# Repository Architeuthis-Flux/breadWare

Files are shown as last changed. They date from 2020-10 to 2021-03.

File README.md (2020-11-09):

# breadWare

Hey guys, here's the PCB layout for the switch matrix board. Those holes should line up with the columns on a breadboard so this whole thing can be soldered directly onto the bottom. I just ordered 10 of these boards (in red soldermask! I've never been patient enough to wait the extra 24-48 hours to do a color other than green) so we can put a few together (I can teach whoever's interested how to hot air solder these surface mount parts) and then get on making those header pins on the sides move the correct number of electrons to make this thing work.
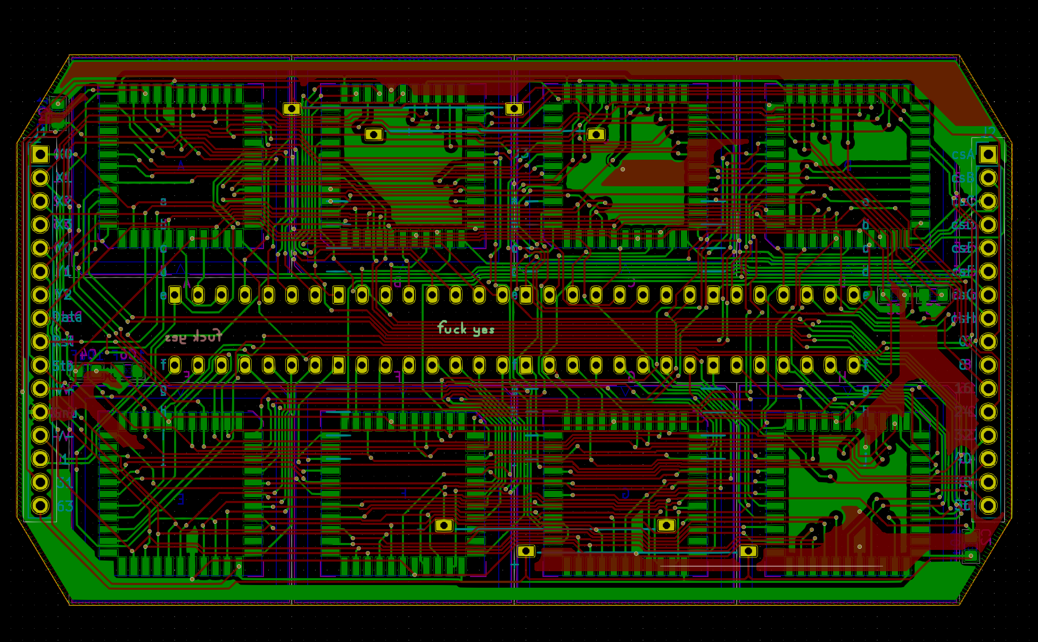
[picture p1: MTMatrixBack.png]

#
 
That white rectangle is roughly the size of a breadboard. We might be able to get the size down if we use [TQFP](https://en.wikipedia.org/wiki/Quad_flat_package) instead of these huge [PLCC](https://en.wikipedia.org/wiki/Chip_carrier#Plastic-leaded_chip_carrier) sockets. Also could someone who reads chinese look through [this datasheet](https://datasheet.lcsc.com/szlcsc/Jiangsu-Qin-Heng-CH446Q_C109471.pdf) for the [CH446Q](http://www.wch-ic.com/products/CH446.html) and tell me if there are any significant differences from [MT8816](http://images.100y.com.tw/pdf_file/41-ZARLINK-MT8816.pdf) that we're using? Because the [JLCPCB](https://jlcpcb.com/) (who is making these boards for us) has the CH446Q in stock and they'll make the board and then solder them on so we can just order fully assembled boards ridiculously cheap (and the chips themselves are ~$1, so like a quarter of the price.)
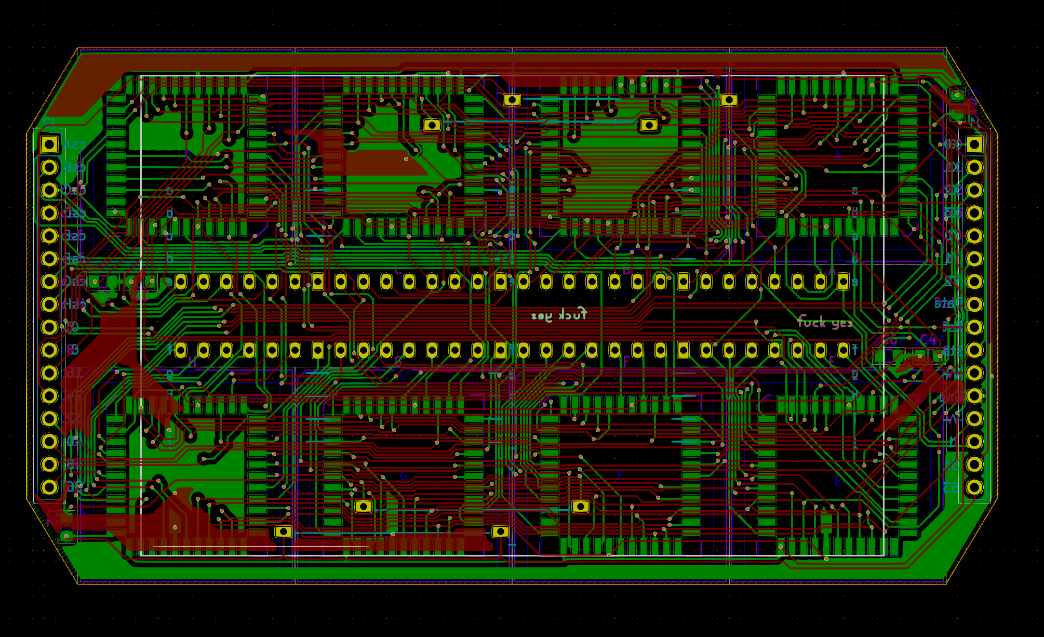
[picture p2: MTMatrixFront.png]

#
 
Notice how some of the pads in the middle (Plated Through Holes or PTH is the correct term just so you know) are more square and others are rounded. The squarer ones means that that pin is connected to the headers on the sides, so it can be used for measurement or power or whatever we decide when we make the control board. Those pins are: 0,1,8,16,24,31,32,40,48,56,63 which is the Y0 pin on each chip plus the ones that end up on the edges of the breadboard (31,63) and 1 because I had an extra header pin available. 
Pin 0 is connected to the Negative rail on the top of the breadboard, 31 is the top Positive rail, 32 is the bottom Negaitve rail, and 63 is the bottom Positive rail. Everything else is where you'd expect it to be.
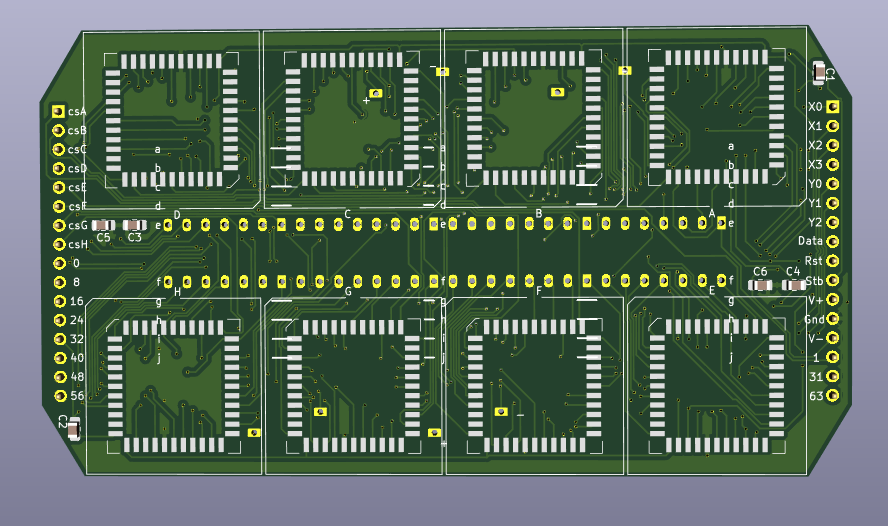
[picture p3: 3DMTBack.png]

#
 
Yes, these pin headers are on the wrong side but I'm not gonna let some stupid auto-generated 3D model tell me which side to solder them on. I might spend some time finding the 3D models for the PLCC sockets and a breadboard so this looks closer to the real thing.
Also, notice the silkscreened lines on the top and bottom are just a bit off from the holes, turns out the power rails on a breadboard arent spaced perfectly on the same grid as the rest of the pins. The line is marked where it would be if the universe made any sense.
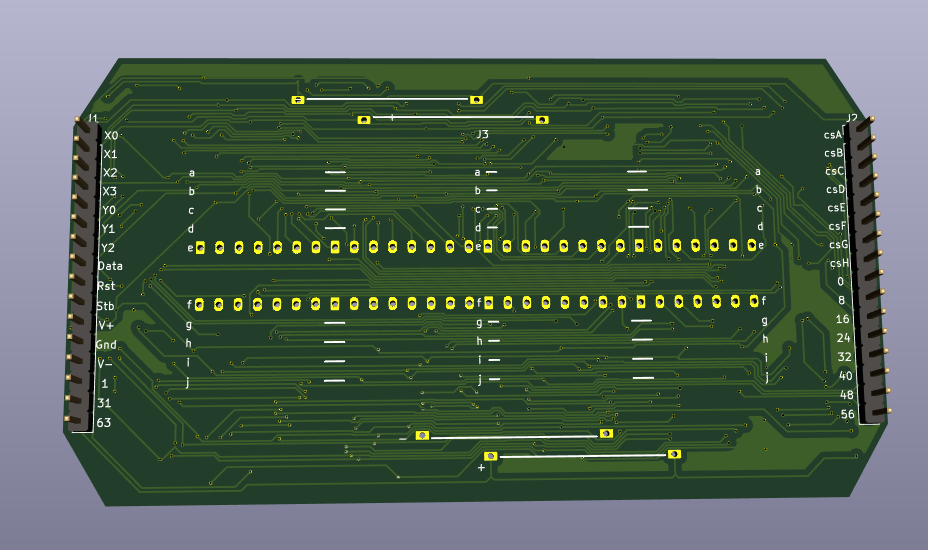
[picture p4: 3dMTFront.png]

#
 
Those letters along the middle correspond to the row labels on a breadboard.
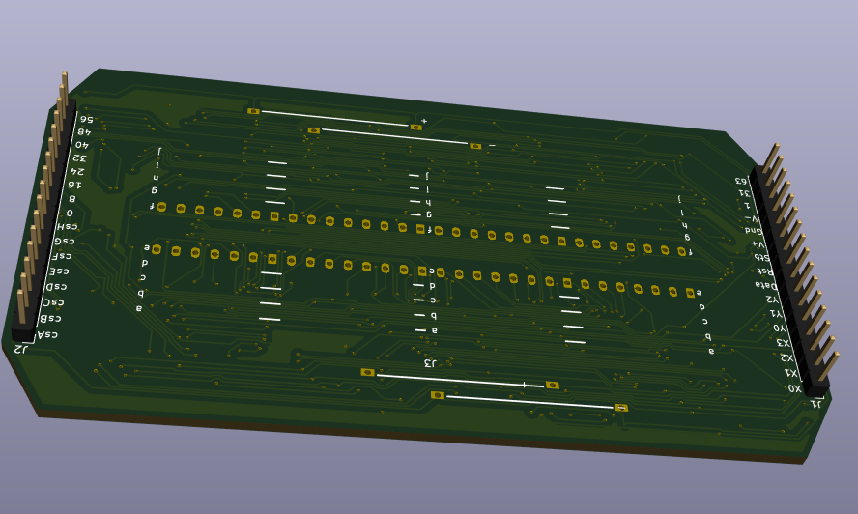
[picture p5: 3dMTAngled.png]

#
  
Here's a zoomed out view of the whole schematic, those blue lines are busses, so they're actually 4 wires bundled together to make it look less messy. This is following JJ's brilliant idea for how to connect everything except I looped the ends back around so they conceptually should be thought of as a ring, If someone wants to map that out on one of those [Ring Lattice Graphs](https://i.imgur.com/oiiyKlz.png), it might make all this easier to visualize.
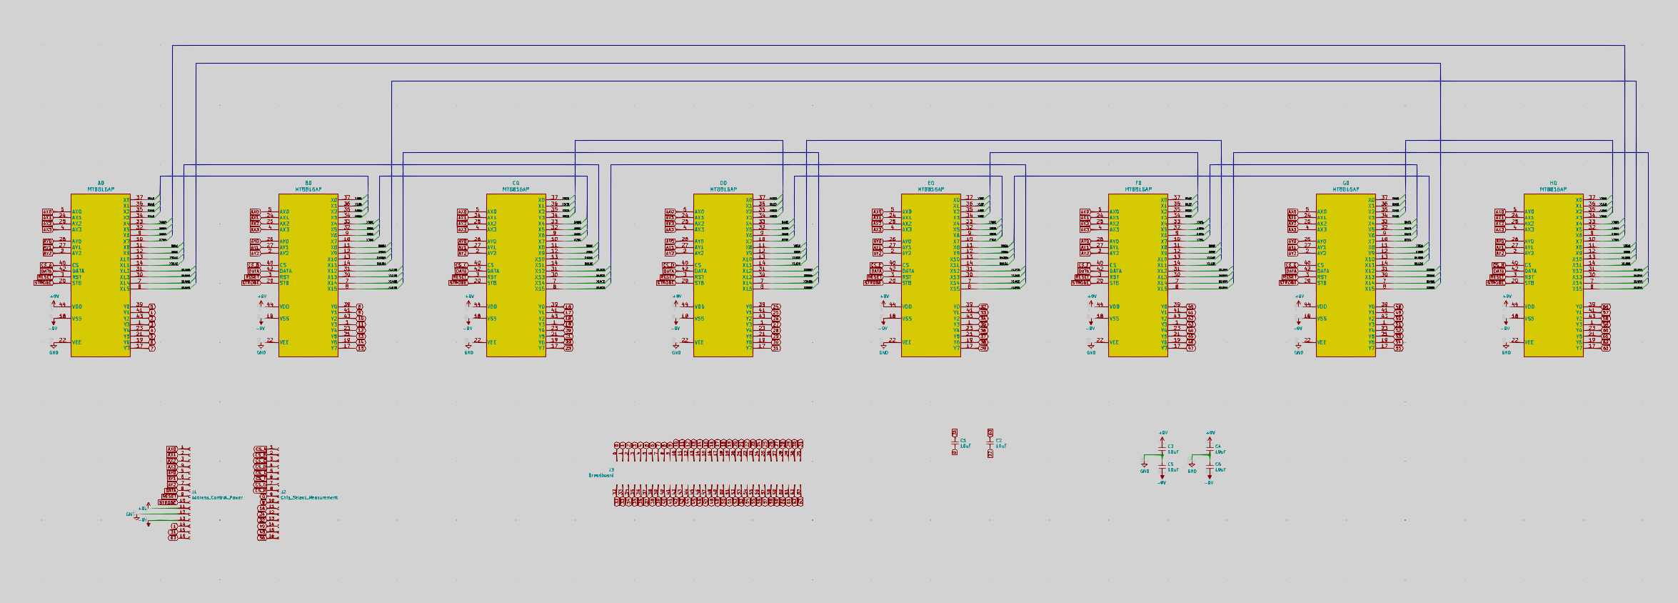
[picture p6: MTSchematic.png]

#

On the left we have the address lines, control lines and power input. Except for the last three with numbers, these are connected to all 8 chips together, so to make just the one we want to control do stuff, we use the Chip Select lines on the right side (labeled CS_A-H) which are wired to each chip individually. If the CS is logic 0 (~0 Volts, LOW, whatever), that chip will ignore everything that's put on the address and control lines because that signal isn't meant for it and these chips ain't no eavesdroppin' bitches. (just for everyone's learning, Chip Select lines seem to almost always be Active Low, meaning they'll ignore everything when that pin is held at logic 1 (5V or 3.3V depending on the chip) which is denoted with a line above, C̅S̅ (or /CS because overlining text is a pain in the ass on a computer. and it's typically spoken as "bar", so "CS Bar" in this case) this chip is unusual because it's Active High.)
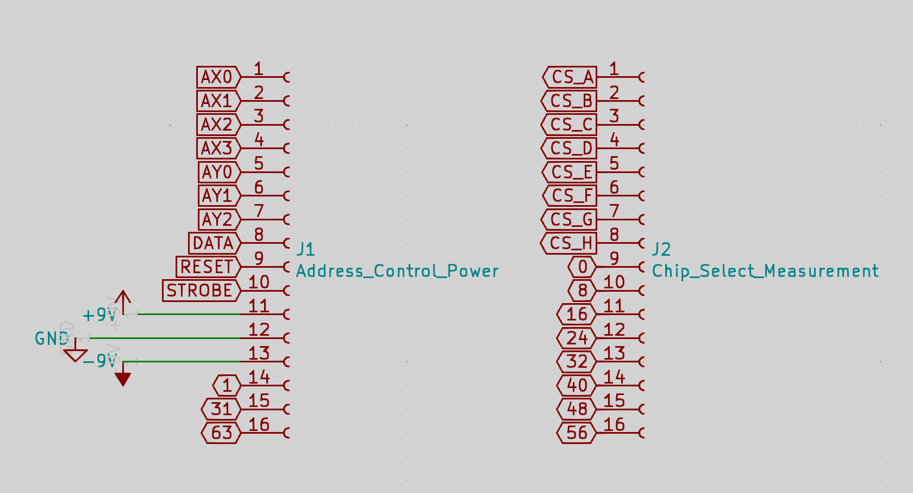
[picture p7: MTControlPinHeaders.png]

#
 
Here's a zoomed part so you can see how I named these interconnects, it goes Pin Name (X0, X1, etc.) then the letters of the two chips it's connecting (in alpabetical order). So the pin labeled X0CD connects pin X0 on chip C to pin X0 on chip D. I had to do this like 5 times to get the wires to always connect to the same pin on both chips, but it should make the software much easier to deal with. 
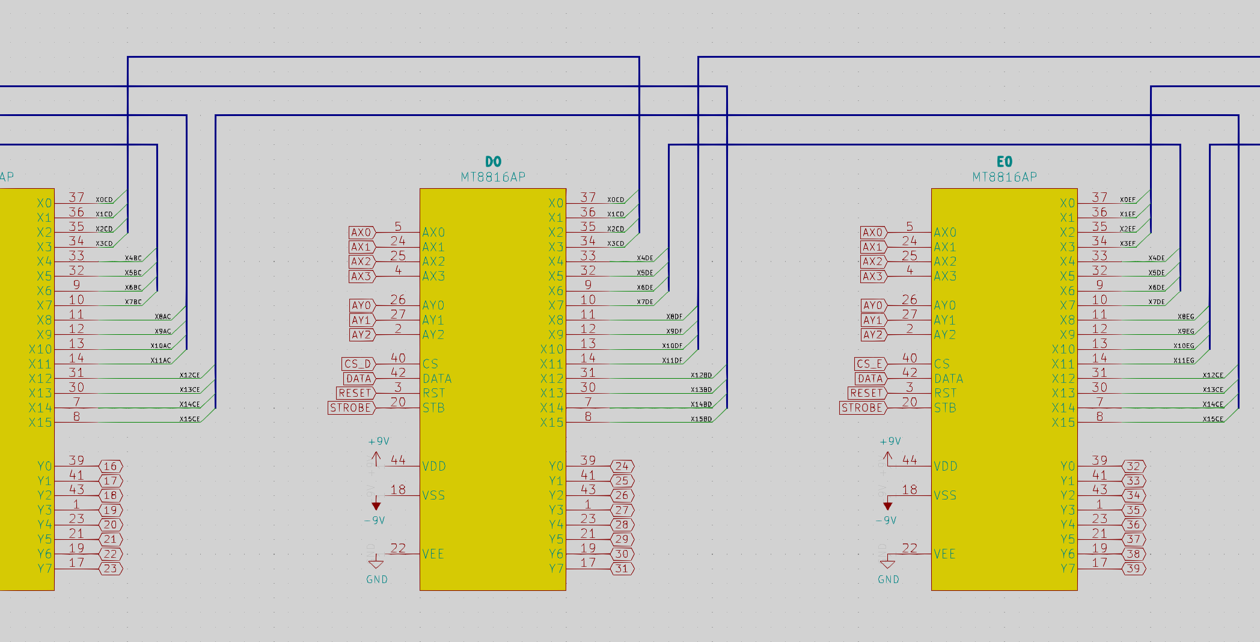
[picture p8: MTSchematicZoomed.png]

#
  
Here's the table I used to figure out which chips are connected where, and this helped me put them all in alphabetical order (because I can't tell you if F is before or after H without singing the alpabet song in my head every time) so the labels are the same on both sides of the wire. Each chip is connected the to the two before and after it. 
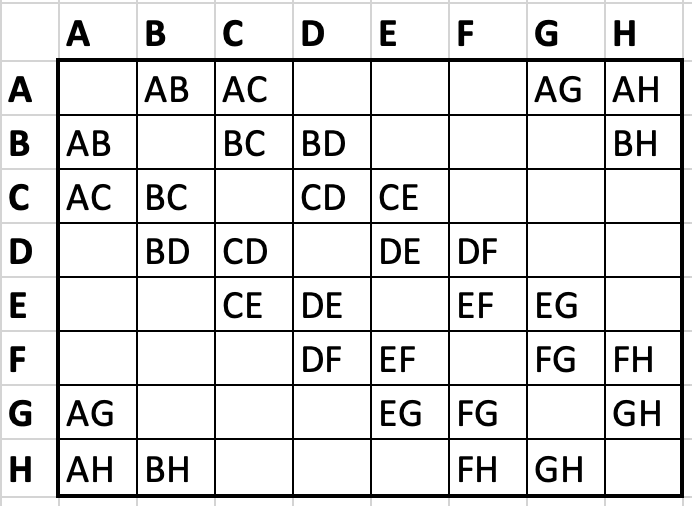
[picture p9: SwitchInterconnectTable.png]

#
One day we will have this piece of paper framed and signed by JJ.
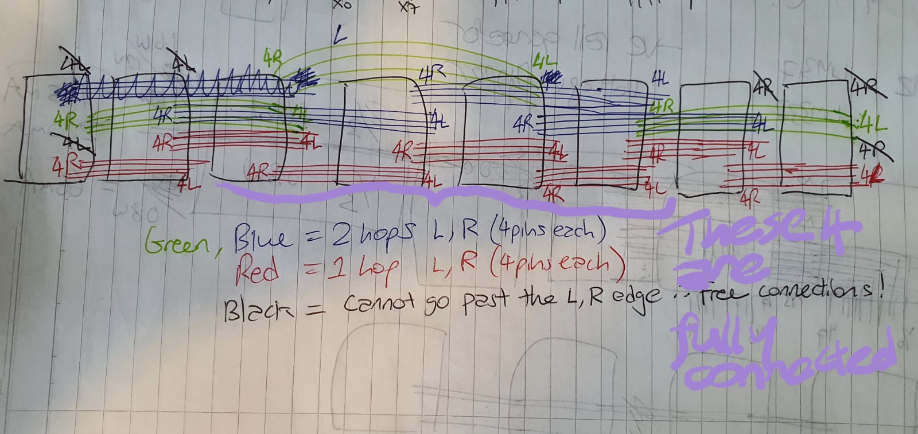
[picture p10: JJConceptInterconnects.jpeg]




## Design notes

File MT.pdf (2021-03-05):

Chip Breadboard
Row

Internal Pin

Number | MT Pin Y | X Pin Chip
Connection
MT Pin X | Notes
A | 0 | 0 | B | 0 | Top GND
A | 1 | 1 | 1 | B | 1
A | 2 | 2 | 2 | B | 2
A | 3 | 3 | 3 | B | 3
A | 4 | 4 | 4 | H | 4
A | 5 | 5 | 5 | H | 5
A | 6 | 6 | 6 | H | 6
A | 7 | 7 | 7 | H | 7
A | C | 8
A | C | 9
A | C | 10
A | C | 11
A | G | 12
A | G | 13
A | G | 14
A | G | 15
B | 8 | 8 | 0 | A | 0
B | 9 | 9 | 1 | A | 1
B | 10 | 10 | 2 | A | 2
B | 11 | 11 | 3 | A | 3
B | 12 | 12 | 4 | C | 4
B | 13 | 13 | 5 | C | 5
B | 14 | 14 | 6 | C | 6
B | 15 | 15 | 7 | C | 7
B | H | 8
B | H | 9
B | H | 10
B | H | 11
B | D | 12
B | D | 13
B | D | 14
B | D | 15
C | 16 | 16 | 0 | D | 0
C | 17 | 17 | 1 | D | 1
C | 18 | 18 | 2 | D | 2
C | 19 | 19 | 3 | D | 3
C | 20 | 20 | 4 | B | 4
C | 21 | 21 | 5 | B | 5
C | 22 | 22 | 6 | B | 6
C | 23 | 23 | 7 | B | 7
C | A | 8
C | A | 9
C | A | 10

C

A | 11
C
E | 12
C
E | 13
C
E | 14
C
E | 15
D | 24 | 24

0

C

0
D | 25 | 25

1

C

1
D | 26 | 26

2

C

2
D | 27 | 27

3

C

3
D | 28 | 28

4

E

4
D | 29 | 29

5

E

5
D | 30 | 30

6

E

6
D | | 31

7

E

7 Top +5V
D

F

8
D

F

9
D
F | 10
D
F | 11
D
B | 12
D
B | 13
D
B | 14
D
B | 15
E | | 32

0

F

0 | Bottom GND
E | 1 | 33

1

F

1
E | 2 | 34

2

F

2
E | 3 | 35

3

F

3
E | 4 | 36

4

D

4
E | 5 | 37

5

D

5
E | 6 | 38

6

D

6
E | 7 | 39

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
G | 10
E
G | 11
E
C | 12
E
C | 13
E
C | 14
E
C | 15
F | 8 | 40

0

E

0
F | 9 | 41

1

E

1
F | 10 | 42

2

E

2
F | 11 | 43

3

E

3
F | 12 | 44

4

G

4
F | 13 | 45

5

G

5
F | 14 | 46

6

G

6
F | 15 | 47

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
D | 10
F
D | 11
F
H | 12
F
H | 13
F
H | 14
F
H | 15
G | 16 | 48

0

H

0
G | 17 | 49

1

H

1
G | 18 | 50

2

H

2
G | 19 | 51

3

H

3
G | 20 | 52

4

F

4
G | 21 | 53

5

F

5
G | 22 | 54

6

F

6
G | 23 | 55

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
E | 10
G
E | 11
G
A | 12
G
A | 13
G
A | 14
G
A | 15
H | 24 | 56

0

G

0
H | 25 | 57

1

G

1
H | 26 | 58

2

G

2
H | 27 | 59

3

G

3
H | 28 | 60

4

A

4
H | 29 | 61

5

A

5
H | 30 | 62

6

A

6
H | | 63

7

A

7 Bottom +5V
H

B

8
H

B

9
H
B | 10
H
B | 11
H
F | 12
H
F | 13
H
F | 14
H
F | 15

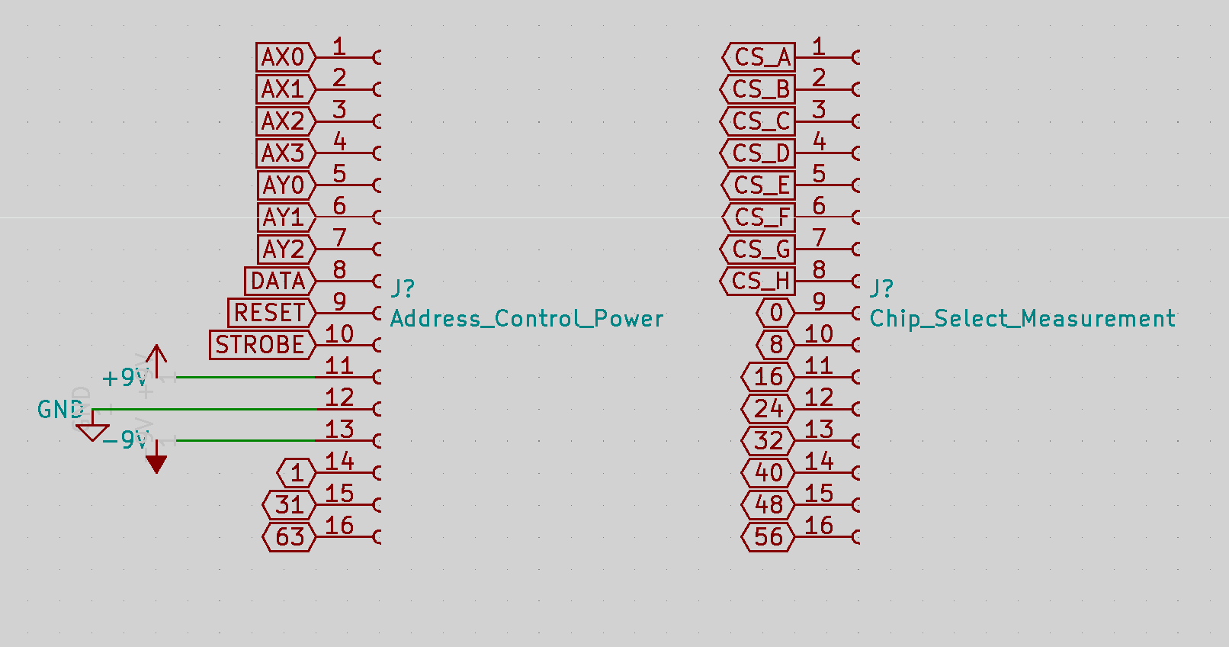
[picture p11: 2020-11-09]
MTMatrixPinHeaders.png

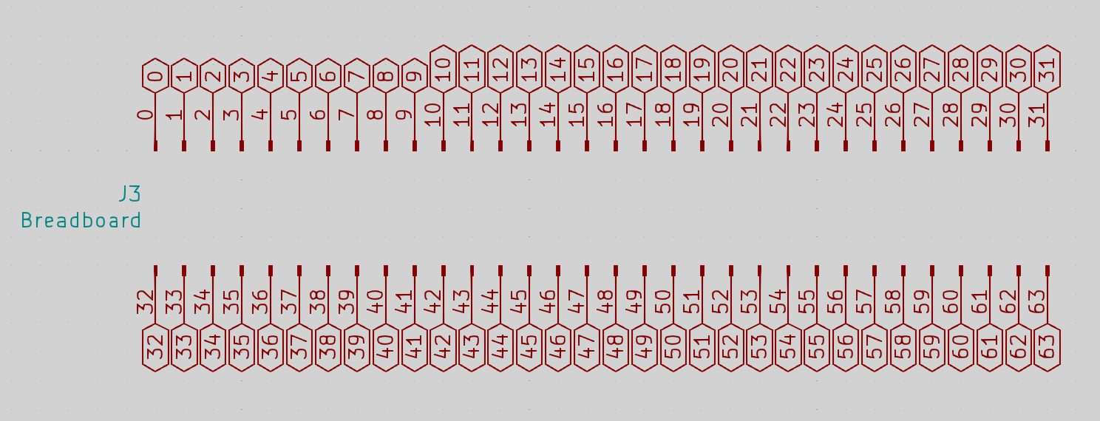
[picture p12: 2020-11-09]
MTBreadboardConnections.png

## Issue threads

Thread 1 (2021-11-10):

Can CH446Q be used?

modi12jin, 2021-11-10:
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

modi12jin, 2021-11-10:
The CH446Q is an 8x16 matrix analog switch chip. The CH446Q contains 128 analog switches which distributed at each intersection of the 8x16 signal path matrix, each analog switch can be turned on or off independently, enabling arbitrary routing of 8x16 signal paths.

modi12jin, 2021-11-21:
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

In parallel address input mode, CH446Q is basically compatible with MT8816, but the package and pins are different. The difference is 8x16
Some pins of the X port of the matrix analog switch are different (or their addressing is different), please refer to the table below for the differences.

@Architeuthis-Flux

Architeuthis-Flux, 2021-11-21:
Yeah, I've looked into that early on but it may be worth getting a few of those to see how they perform. The serial addressing would be really nice to make everything a bit simpler, and the smaller package would allow me to fit more of them on each board. I vaguely remember the operating voltage being lower but I'll pull up both datasheets to compare. @modi12jin Any chance you've found one in english?

modi12jin, 2021-11-22:
@Architeuthis-Flux I did not find the English version of the manual, but I made some efforts to translate the Chinese manual into the English version of the manual.

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

[CH446DS1_English.pdf](https://github.com/Architeuthis-Flux/breadWare/files/7579018/CH446DS1_English.pdf)

modi12jin, 2021-11-22:
# Analog switch chip

| model  | Function description | Typical power supply (VDD) | Typical internal resistance | Typical bandwidth | Signal voltage | Encapsulation | Application signal recommendation |
| :----: | :------------------: | :------------------------: | :-------------------------: | :---------------: | :------------: | :-----------: | :-------------------------------: |
| CH446Q |      16*8 array      |           5V/12V           |             50Ω             |       50MHz       |    VEE~VDD     |    LQFP44     |              30Mbps               |
| CH446X |      24*5 array      |           5V/12V           |             50Ω             |       50MHz       |    VEE~VDD     |    LQFP44     |              30Mbps               |

Architeuthis-Flux, 2021-11-22:
Thanks for the translation, it's much nicer to read than the raw Google Translate version. I really appreciate it.

I think I'm going to try out a version with 12 CH446X's on the top board, so every 5 breadboard rows are the Y pins and then I'll have 24 backend connections to route 2 lines to every other chip and the 2 extra lines go to the special function crosspoint chip on the bottom board (or power and ground, and then I'd need to come up with a new scheme for routing special functions, maybe I'll add another chip that handles the power rails and special functions.) I guess logically it would be similar to using 8 CH446Q's, I need to map it all out on paper and see if I can come up with a clever solution for all that.

I'm assuming you're in China, and I'm wondering if you might have a way of finding these chips for less than the $2.30 USD each that I just payed on Aliexpress.

Feel free to join the project on [Hackaday.io](https://hackaday.io/project/180394-breadware) so we can use the project chat too.

modi12jin, 2021-11-25:
@Architeuthis-Flux You guessed it, I was in China, and it was about $1.3 if I bought it on Chinese Taobao. If you buy in large quantities, it is recommended to find official sales or large distributors, the price will be lower because of the quantity you buy.

modi12jin, 2021-11-26:
@Architeuthis-Flux What kind of MCU is used to control CH446X? It only supports serial communication. I can't see how to reuse and replace SPI. You may need 48 (12×4) GPIOs.

I plan to use ESP32-C3 as a controlled terminal. For the control end, I may need CH446Q (because the number of pins is just right), I need ten CH446Q. The MCU on the control side needs 40 (4×10) GPIOs.

modi12jin, 2021-11-26:
@Architeuthis-Flux What kind of MCU is used to control CH446X? It only supports serial communication. I can't see how to reuse and replace SPI. You may need 48 (12×4) GPIOs.

I plan to use ESP32-C3 as a controlled terminal. For the control end, I may need CH446Q, I need 8 CH446Q. The MCU on the control side needs 32 (4×8) GPIOs.

Architeuthis-Flux, 2021-11-26:
@modi12jin It's hard to be 100% sure from these short datasheets, but if I understand it correctly once you set an address for each chip, they can be bussed together and all share the same 4 lines ignoring any command that doesn't start with that chip's 7 (or 8) bit address. So if you set the address before soldering them onto the board, you could control them all with only 4 pins. As for how non-volatile that stored address is, I don't know. To be safe it might be worth coming up with a way to individually set them at startup, but that adds 12 (or 24) more pins unless come clever multiplexing scheme is used.

modi12jin, 2021-11-26:
@Architeuthis-Flux

```
https://www.1688.com/
```

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

modi12jin, 2021-11-28:
@Architeuthis-Flux I plan to test it, so I drew a simple CH446Q adapter board.

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

modi12jin, 2021-12-08:
```
#include <Arduino.h>

#define RST 4
#define STB 19
#define SK  18
#define DAT 23

#define LED 5

//CH446Q初始化
void CH446Q_Init(){
  pinMode(STB,OUTPUT);
  pinMode(DAT,OUTPUT);
  pinMode(SK,OUTPUT);
  pinMode(RST,OUTPUT);
  digitalWrite(RST,1);
  delay(50);
	digitalWrite(RST,0);
}

//发送地址和状态
void CH446Q_SendAddr_Switch(uint8_t addr,bool data){
  uint8_t ByteCnt;

  digitalWrite(STB,0);
  digitalWrite(DAT,0);

  delay(20);

  for(ByteCnt=0;ByteCnt<8;ByteCnt++){
    digitalWrite(SK,0);
    delay(10);

    if(addr & 0x80){
      digitalWrite(DAT,1);
    }else{
      digitalWrite(DAT,0);
    }
    digitalWrite(SK,1);
    delay(50);
    addr <<=1;
  }

  digitalWrite(SK,0);

  if(data == 1){
    digitalWrite(DAT,1);
  }else{
    digitalWrite(DAT,0);
  }

  delay(40);
  digitalWrite(STB,1);
  delay(20);
  digitalWrite(STB,0);
  delay(20);
}

void setup() {
  CH446Q_Init();
  CH446Q_SendAddr_Switch(0x01,1); //Y0-X1连接
  CH446Q_SendAddr_Switch(0x7F,1); //Y7-X15连接
  pinMode(LED,OUTPUT);
}

void loop() {
  digitalWrite(LED,1);
  delay(1000);
  digitalWrite(LED,0);
  delay(1000);
}
```

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

@Architeuthis-Flux  Test success! I haven't tested whether it can be reused

modi12jin, 2021-12-10:
> CH446Q.cpp

```
#include "Arduino.h"
#include "CH446Q.h"
#include "SPI.h"

CH446Q::CH446Q(int8_t rst,int8_t stb,int8_t sk,int8_t dat){
     _rst=rst;
     _stb=stb;
     _sk=sk;
     _dat=dat;
}

//CH446Q复位
void CH446Q::Reset(void){
  digitalWrite(_rst,1);
  delay(50);
  digitalWrite(_rst,0);
}

//CH446Q初始化
void CH446Q::Init(void){
  pinMode(_stb,OUTPUT);
  pinMode(_rst,OUTPUT);
  pinMode(_sk,OUTPUT);
  pinMode(_dat,OUTPUT);
  CH446Q::Reset();
}

//发送地址和状态
void CH446Q::SendAddr_Switch(uint8_t addr,bool data){
  uint8_t ByteCnt;

  digitalWrite(_stb,0);
  digitalWrite(_dat,0);

  delay(20);

  for(ByteCnt=0;ByteCnt<8;ByteCnt++){
    digitalWrite(_sk,0);
    delay(10);

    if(addr & 0x80){
      digitalWrite(_dat,1);
    }else{
      digitalWrite(_dat,0);
    }
    digitalWrite(_sk,1);
    delay(50);
    addr <<=1;
  }

  digitalWrite(_sk,0);

  if(data == 1){
    digitalWrite(_dat,1);
  }else{
    digitalWrite(_dat,0);
  }

  delay(40);
  digitalWrite(_stb,1);
  delay(20);
  digitalWrite(_stb,0);
  delay(20);
}
```

> CH446Q.h

```
#ifndef  __CH446Q_H__
#define  __CH446Q_H__

#include "CH446Q.h"

#define Y0_X0 0x00
#define Y0_X1 0x01
#define Y0_X2 0x02
#define Y0_X3 0x03
#define Y0_X4 0x04
#define Y0_X5 0x05
#define Y0_X6 0x06
#define Y0_X7 0x07
#define Y0_X8 0x08
#define Y0_X9 0x09
#define Y0_X10 0x0A
#define Y0_X11 0x0B
#define Y0_X12 0x0C
#define Y0_X13 0x0D
#define Y0_X14 0x0E
#define Y0_X15 0x0F
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
Architeuthis-Flux, 2021-12-12:
Nice, I really like the idea of defining every internal connection as a hex value. That will make saving and reloading board states soooo much easier, and points to a solution for disconnecting rows.

It's also interesting that it doesn't have a messed up truth table (as far as I can tell) like the MT8816, which swaps X12 and X13 with X6 and X7 (or something like that, it's been a while) so you have to change that if you want to just send bytes to a port as hex.

I think I may use a couple (or 3) of these CH446s for the control board (to save space) and leave the MT8816s on the top side, after some discussion with non-techy people, they all liked the weight that those huge PLCC chips add to it. And having a huge ceramic package might help dissipate more heat so we can run them a bit further out of spec than we already are.

I'll get some work done on it soon but Christmas has me flying between my hometown and Mexico way too much to be consistent lately.

modi12jin, 2021-12-20:
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

https://github.com/dotcypress/fpgb

@Architeuthis-Flux I don't know if you have seen this warehouse, and his idea may have a place worth learning.

modi12jin, 2022-01-13:
https://user-images.githubusercontent.com/40233017/149251092-57c91428-12dc-49fe-ad24-c75a98ce2fa8.mp4

@Architeuthis-Flux (ST7789_SPI_240*240) There is no distortion in the case of 40MHZ, and the screen is directly black at 80MHZ.

modi12jin, 2022-01-19:
https://user-images.githubusercontent.com/40233017/150080595-8f7e2423-76d5-4e99-8341-5ee01db7cd42.mp4

modi12jin, 2022-01-19:
@Architeuthis-Flux  found that CH446Q is not very suitable for switch connection of power and ground, only for signal switch connection (because the current is too small). I have tested that the current cannot drive the ST7789 screen, but directly connecting the 3V3 on the ESP32 minimum system board can make it work normally

atlaste, 2023-06-22:
@modi12jin @Architeuthis-Flux The english datasheet of the CH446Q is available on the website here: http://www.wch-ic.com/downloads/CH446DS1_PDF.html

The pins seem 12v tolerant and it should be able to switch roughly 15mA of current if you drive them at 12v. Otherwise it's way less. That's at least how I interpret table 6.3. However, then you do need 5v logic to switch them, so an ESP32 that only does 3.3v won't cut it... easy enough to solve tho.

Architeuthis-Flux, 2023-06-22:
@atlaste Yeah, the specs do get way better as supply voltage goes up and temperature goes down.
On the [Jumperless](https://github.com/Architeuthis-Flux/Jumperless) I'm actually driving them a few volts higher than they say you can in the Absolute Maximum Ratings (~+9V - -8.5V) and they seem to tolerate it fine. And signaling is done with an RP2040 at 3.3V which also works great.

And I've been testing pushing 100mA through them and haven't blown one up yet somehow.

There's also a very elusive app note out there somewhere that I can't find right now.

@modi12jin In my experience, when weird things are happening with getting a huge voltage sag when pulling any current, it's because I've messed up the addressing somehow and so a bunch of connections have been made that shouldn't be. So you end up with a voltage divider situation.

atlaste, 2023-06-23:
@Architeuthis-Flux Yes I noticed that while looking at the schematics.

When using 9v/-8.5v the VDD-GND=9v, so I'm not really surprised that you can drive them with 3.3v. VIH=2v for VDD-GND=5v and 3.3v for VDD-GND=12v; assuming linear scaling that means they should trigger at roughly 2.75v. TTL is at 2.7v so that seems to be just fine. They should go up to 100 mA, as long as you push <= 15 mA per pin according to the datasheet.

For most applications you probably don't even need the -8.5v, since you're only 0-9v through in reality?

I'd like to switch them at 12v for my pet project. But 3.3v for VIh is not going to cut it I suppose, so I guess that's not going to be working with a RP2040.

Closed 2021-11-22.

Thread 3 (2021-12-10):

About the GUI interaction method?

modi12jin, 2021-12-10:
Let them establish the connection relationship in a way similar to the schematic diagram, similar to the Fritzing software put the module on the breadboard to establish the position relationship, and then output the specific position relationship and connection relationship code, and send it to the MCU through the serial port or wirelessly.

@Architeuthis-Flux What do you think of this way?

modi12jin, 2021-12-20:
https://user-images.githubusercontent.com/40233017/146791348-42de94b1-a7a6-4590-95be-d654caa736ef.mp4

https://www.hackster.io/news/the-schemaboard-allows-users-to-inspect-and-assemble-circuits-on-breadboards-83fe797d8dcc

@Architeuthis-Flux

Architeuthis-Flux, 2021-12-20:
That's rad. I'm trying to figure out how they got those backlights to look so even. It looks like they actually built the breadboard from scratch to make that work, which might be a solid option for us. Both for longevity and giving us more space in the board that's currently just filled with plastic. If we made the top of the breadboard out of a PCB we could do a ton of cool shit with displaying what's going on.
Or if we ant to keep the top as a regular breadboard we could drill some holes in the little metal clips and put an LED in each one or light them from the side with one of those side lit diffusers above the clips. Let's mess around and try to find an elegant way to do that. The next revision of breadWare will probably have a 4 layer top board to make room for stuff like that. Because that's definitely something that would add a ton of utility.

modi12jin, 2021-12-20:
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

https://dl.acm.org/doi/10.1145/3379337.3415887
@Architeuthis-Flux

modi12jin, 2022-01-07:
@Architeuthis-Flux I don’t know if you have read this, maybe its code has reference value

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

 https://github.com/gatecat/BreadboardSim

modi12jin, 2022-01-25:
https://user-images.githubusercontent.com/40233017/151078972-178a8193-b344-44d4-b7f2-afcd85ade050.mp4

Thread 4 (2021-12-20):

How to prevent damage to the device by connecting the wrong power supply and GND position?

modi12jin, 2021-12-20:
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

https://blog.oshpark.com/2016/11/28/bfuse-electronic-fuse-for-breadboard/

@Architeuthis-Flux

Architeuthis-Flux, 2021-12-21:
That’s a solid idea. I think we can take care of a few things at the same time if we have a good system to monitor current separately on as many lines as possible coming from the special function crosspoint switches. But also we cant assume people won’t use any physical jumpers.

There also might be some clever way to do that in the analog domain; especially because the power supplies are actually op amps. Like a zener diode in parallel with a current sense resistor going to the the inverting input or something like that.

ppeetteerrs, 2022-04-09:
I think a load switch like TPS22993 might be a potential solution to your power line and ground issue? You can also use them together with a power mux like TPS2116 to save the number of chips need.

Closed 2021-12-21.

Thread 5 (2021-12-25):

Use BTB connector to reduce iteration cost

modi12jin, 2021-12-25:
ch446Q uses the BTB connector to switch, so as to avoid unnecessary iteration costs.  I think this is helpful for us to iterate, and the MCU can also be made into a BTB format similar to the Raspberry Pi CM4 calculation module

modi12jin, 2022-01-06:
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

modi12jin, 2022-01-06:
https://user-images.githubusercontent.com/40233017/148383245-ec4de99c-7cd6-4b7a-910d-35b1f2fd79d6.mp4

@Architeuthis-Flux  This is my preliminary design, there is still a lot of work I haven’t done, but it outlines the outline

modi12jin, 2022-01-16:
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

@Architeuthis-Flux I finally figured out that soldering a breadboard directly to a PCB is very difficult and unreliable. This is a lesson, I'm going to switch to using the header as a "breadboard"

modi12jin, 2022-01-21:
https://user-images.githubusercontent.com/40233017/150609096-aba0e7db-122b-4196-8105-b468b0b1b940.mp4

modi12jin, 2022-01-25:
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
@Architeuthis-Flux I haven't had time to test, currently known problems: the power rail and ground problems are not solved (the later version adds special holes to solve it, which may add some jumpers). The BTB connector is not stable enough (solved by increasing the number or size of btb or  Find a new and better connection method).

modi12jin, 2022-02-24:
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

This is the third iteration

modi12jin, 2022-02-24:
https://user-images.githubusercontent.com/40233017/155560761-5f940a39-fcb3-4a87-a3b1-aa1ec65a76de.mp4

modi12jin, 2022-02-25:
https://user-images.githubusercontent.com/40233017/155657763-b011a958-a4a0-45d6-9b67-e6055ad4a762.mp4

 There is no need to connect other transmission data lines except for power supply and ground.

modi12jin, 2022-02-26:
https://user-images.githubusercontent.com/40233017/155833326-c64ef500-1cf4-4056-978e-785e389e9b9e.mp4

SPI emulation

modi12jin, 2022-02-26:
https://user-images.githubusercontent.com/40233017/155833394-43fbb278-0505-4efa-8b4d-79b69376d293.mp4

https://user-images.githubusercontent.com/40233017/155833398-74d31df3-4f05-4869-ac1c-8bfa46bf256d.mp4

There is a problem with the hardware SPI, which usually doesn't work. It may be a wiring problem or other problem, I don't have a logic analyzer and oscilloscope here so I can't clear the specific situation.

Closed 2022-01-28.

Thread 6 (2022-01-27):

provide inspiration

modi12jin, 2022-01-27:
# Schematic-o-matic Automatically draw a KiCad schematic for a circuit prototyped on a breadboard.

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

https://user-images.githubusercontent.com/40233017/151304046-604d47a4-871f-412b-b506-1d4b1b34bd14.mp4

https://create.arduino.cc/projecthub/nickbild/schematic-o-matic-b6406f

https://github.com/nickbild/schematic-o-matic

@Architeuthis-Flux Maybe this provides some inspiration

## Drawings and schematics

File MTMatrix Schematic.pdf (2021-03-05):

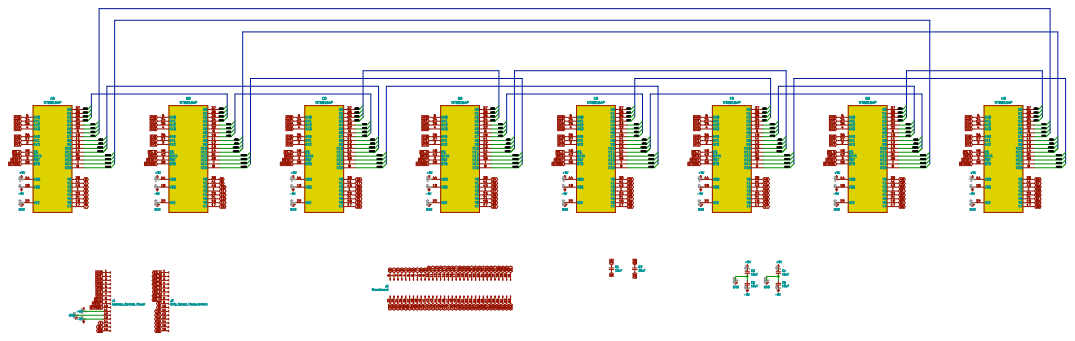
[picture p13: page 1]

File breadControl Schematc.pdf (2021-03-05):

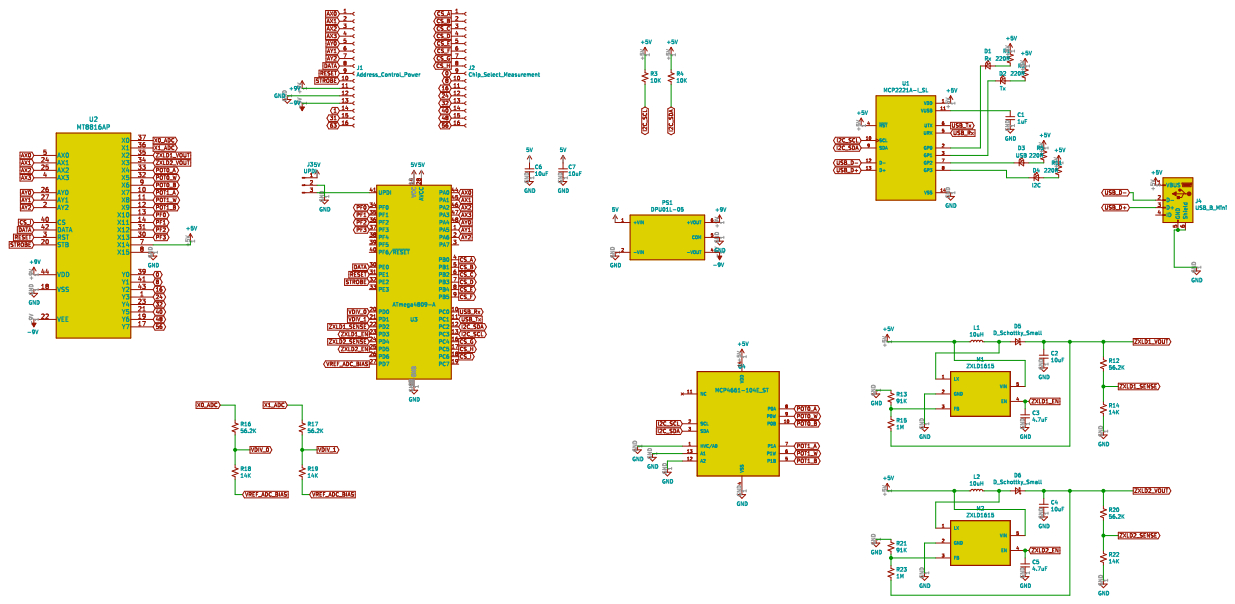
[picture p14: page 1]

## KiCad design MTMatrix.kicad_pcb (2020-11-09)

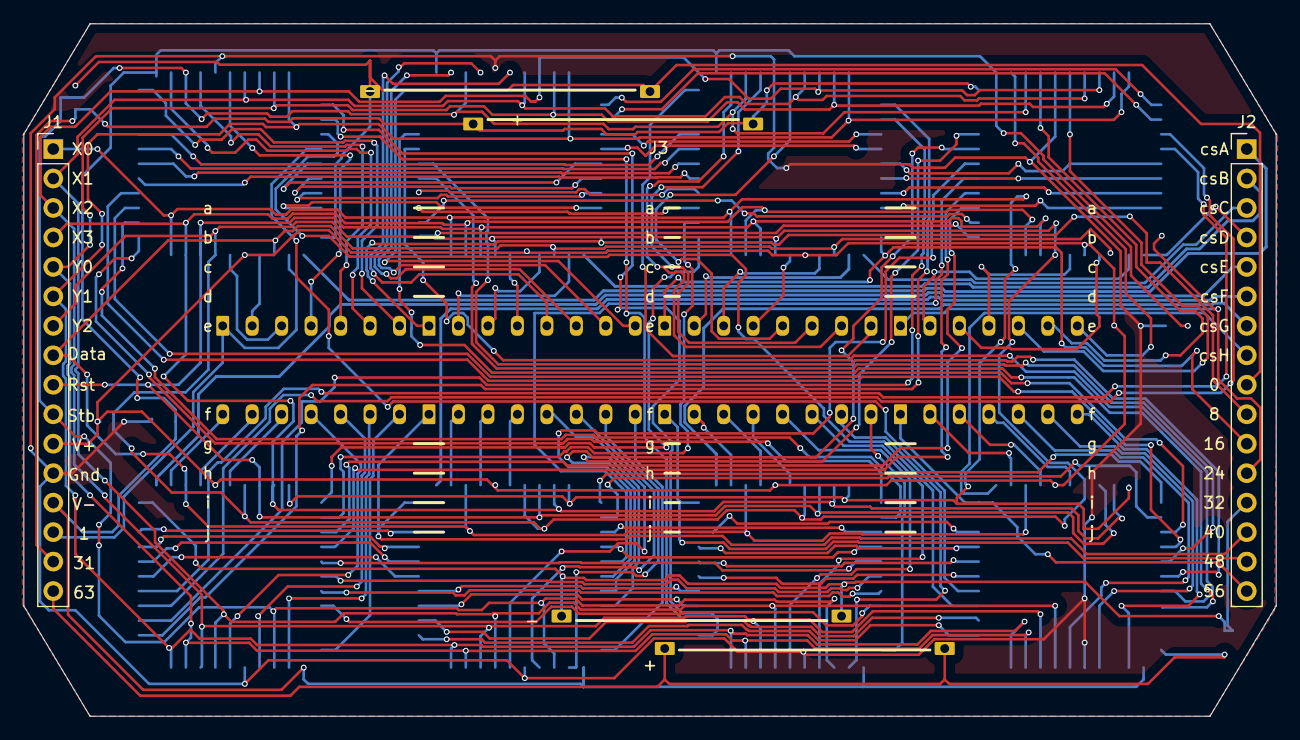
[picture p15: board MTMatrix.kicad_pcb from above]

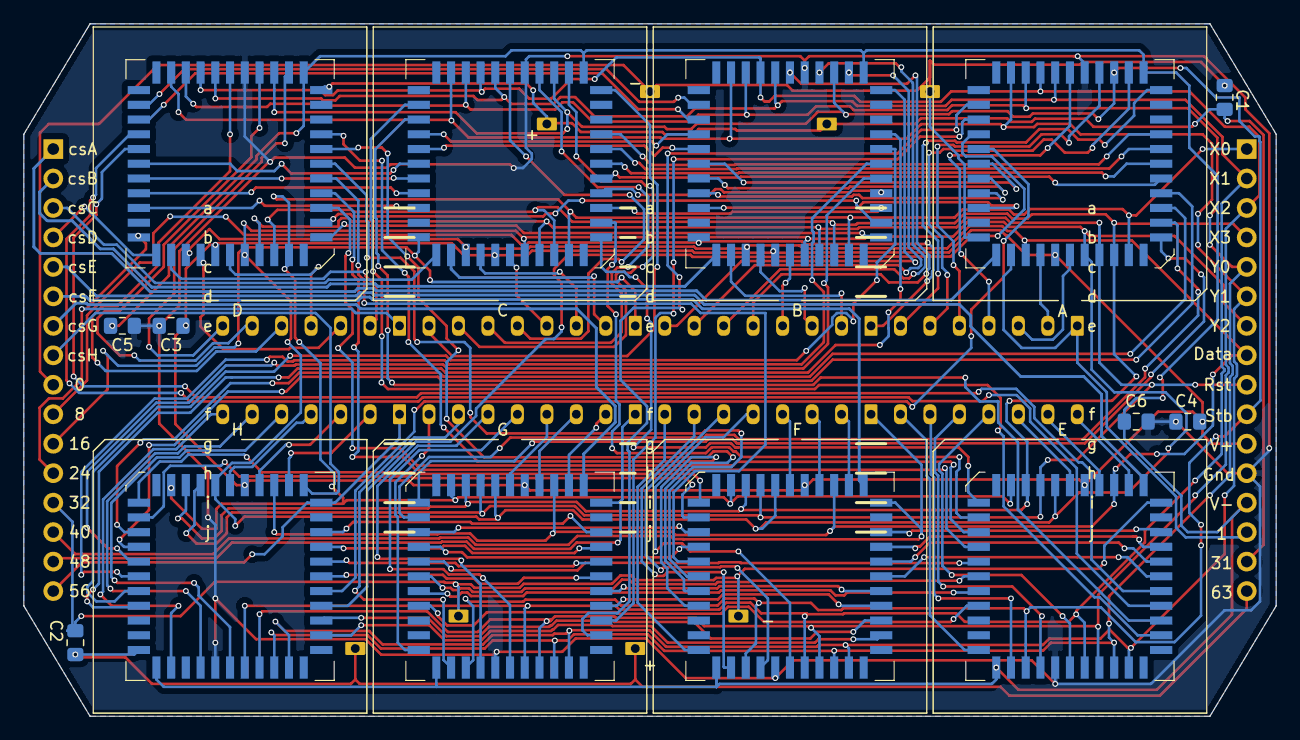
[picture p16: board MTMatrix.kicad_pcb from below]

Board: 2 copper layers, 107.9 x 59.7 mm, 17 parts (14 on the bottom side), 149 nets.

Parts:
A: MT8816AP; PLCC-44_SMD-Socket
B: MT8816AP; PLCC-44_SMD-Socket
C: MT8816AP; PLCC-44_SMD-Socket
C1, C2, C3, C4, C5, C6: 10uF; C_0805_2012Metric_Pad1.15x1.40mm_HandSolder
D: MT8816AP; PLCC-44_SMD-Socket
E: MT8816AP; PLCC-44_SMD-Socket
F: MT8816AP; PLCC-44_SMD-Socket
G: MT8816AP; PLCC-44_SMD-Socket
H: MT8816AP; PLCC-44_SMD-Socket
J1: Address_Control_Power; PinHeader_1x16_P2.54mm_Vertical
J2: Chip_Select_Measurement; PinHeader_1x16_P2.54mm_Vertical
J3: Breadboard; Breadboard_Top

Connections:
0: A.39, C1.2, J2.9, J3.0
1: A.41, J1.14, J3.1
2: A.43, J3.2
3: A.1, J3.3
4: A.23, J3.4
5: A.21, J3.5
6: A.19, J3.6
7: A.17, J3.7
8: B.39, J2.10, J3.8
9: B.41, J3.9
10: B.43, J3.10
11: B.1, J3.11
12: B.23, J3.12
13: B.21, J3.13
14: B.19, J3.14
15: B.17, J3.15
16: C.39, J2.11, J3.16
17: C.41, J3.17
18: C.43, J3.18
19: C.1, J3.19
20: C.23, J3.20
21: C.21, J3.21
22: C.19, J3.22
23: C.17, J3.23
24: D.39, J2.12, J3.24
25: D.41, J3.25
26: D.43, J3.26
27: D.1, J3.27
28: D.23, J3.28
29: D.21, J3.29
30: D.19, J3.30
31: C1.1, D.17, J1.15, J3.31
32: C2.2, E.39, J2.13, J3.32
33: E.41, J3.33
34: E.43, J3.34
35: E.1, J3.35
36: E.23, J3.36
37: E.21, J3.37
38: E.19, J3.38
39: E.17, J3.39
40: F.39, J2.14, J3.40
41: F.41, J3.41
42: F.43, J3.42
43: F.1, J3.43
44: F.23, J3.44
45: F.21, J3.45
46: F.19, J3.46
47: F.17, J3.47
48: G.39, J2.15, J3.48
49: G.41, J3.49
50: G.43, J3.50
51: G.1, J3.51
52: G.23, J3.52
53: G.21, J3.53
54: G.19, J3.54
55: G.17, J3.55
56: H.39, J2.16, J3.56
57: H.41, J3.57
58: H.43, J3.58
59: H.1, J3.59
60: H.23, J3.60
61: H.21, J3.61
62: H.19, J3.62
63: C2.1, H.17, J1.16, J3.63
+9V: A.44, B.44, C.44, C3.1, C4.1, D.44, E.44, F.44, G.44, H.44, J1.11
-9V: A.18, B.18, C.18, C5.2, C6.2, D.18, E.18, F.18, G.18, H.18, J1.13
/X0AB: A.37, B.37
/X0CD: C.37, D.37
/X0EF: E.37, F.37
/X0GH: G.37, H.37
/X1AB: A.36, B.36
/X1CD: C.36, D.36
/X1EF: E.36, F.36
/X1GH: G.36, H.36
/X2AB: A.35, B.35
/X2CD: C.35, D.35
/X2EF: E.35, F.35
/X2GH: G.35, H.35
/X3AB: A.34, B.34
/X3CD: C.34, D.34
/X3EF: E.34, F.34
/X3GH: G.34, H.34
/X4AH: A.33, H.33
/X4BC: B.33, C.33
/X4DE: D.33, E.33
/X4FG: F.33, G.33
/X5AH: A.32, H.32
/X5BC: B.32, C.32
/X5DE: D.32, E.32
/X5FG: F.32, G.32
/X6AH: A.9, H.9
/X6BC: B.9, C.9
/X6DE: D.9, E.9
/X6FG: F.9, G.9
/X7AH: A.10, H.10
/X7BC: B.10, C.10
/X7DE: D.10, E.10
/X7FG: F.10, G.10
/X8AC: A.11, C.11
/X8BH: B.11, H.11
/X8DF: D.11, F.11
/X8EG: E.11, G.11
/X9AC: A.12, C.12
/X9BH: B.12, H.12
/X9DF: D.12, F.12
/X9EG: E.12, G.12
/X10AC: A.13, C.13
/X10BH: B.13, H.13
/X10DF: D.13, F.13
/X10EG: E.13, G.13
/X11AC: A.14, C.14
/X11BH: B.14, H.14
/X11DF: D.14, F.14
/X11EG: E.14, G.14
/X12AG: A.31, G.31
/X12BD: B.31, D.31
/X12CE: C.31, E.31
/X12FH: F.31, H.31
/X13AG: A.30, G.30
/X13BD: B.30, D.30
/X13CE: C.30, E.30
/X13FH: F.30, H.30
/X14AG: A.7, G.7
/X14BD: B.7, D.7
/X14CE: C.7, E.7
/X14FH: F.7, H.7
/X15AG: A.8, G.8
/X15BD: B.8, D.8
/X15CE: C.8, E.8
/X15FH: F.8, H.8
AX0: A.5, B.5, C.5, D.5, E.5, F.5, G.5, H.5, J1.1
AX1: A.24, B.24, C.24, D.24, E.24, F.24, G.24, H.24, J1.2
AX2: A.25, B.25, C.25, D.25, E.25, F.25, G.25, H.25, J1.3
AX3: A.4, B.4, C.4, D.4, E.4, F.4, G.4, H.4, J1.4
AY0: A.26, B.26, C.26, D.26, E.26, F.26, G.26, H.26, J1.5
AY1: A.27, B.27, C.27, D.27, E.27, F.27, G.27, H.27, J1.6
AY2: A.2, B.2, C.2, D.2, E.2, F.2, G.2, H.2, J1.7
CS_A: A.40, J2.1
CS_B: B.40, J2.2
CS_C: C.40, J2.3
CS_D: D.40, J2.4
CS_E: E.40, J2.5
CS_F: F.40, J2.6
CS_G: G.40, J2.7
CS_H: H.40, J2.8
DATA: A.42, B.42, C.42, D.42, E.42, F.42, G.42, H.42, J1.8
GND: A.22, B.22, C.22, C3.2, C4.2, C5.1, C6.1, D.22, E.22, F.22, G.22, H.22, J1.12
RESET: A.3, B.3, C.3, D.3, E.3, F.3, G.3, H.3, J1.9
STROBE: A.20, B.20, C.20, D.20, E.20, F.20, G.20, H.20, J1.10

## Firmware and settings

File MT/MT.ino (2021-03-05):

#//include <Wire.h>
#include "breadWareDefines.h"
//#include "matrixArrays.h"
#include "Globals.h"



void setup() {

  Serial1.begin (115200);
  PORTMUX.TWISPIROUTEA = 0b00100000;
  PORTMUX.USARTROUTEA = 0b11000011;

  //Serial1.println (PORTMUX.TWISPIROUTEA,BIN);
  //Serial.print (PORTMUX.TWISPIROUTEA,BIN);
  /* PORTA.DIR = 0b01111111;
    PORTA.OUT    = 0b00000000;

    PORTB.DIR = 0b00111111;
    PORTB.OUT    = 0b00000000;

    PORTC.DIR |= 0b01110000; //so I dont mess with I2C or UART
    PORTC.OUT    &= 0b00001111;

    PORTD.DIR = 0b10101000;
    PORTD.OUT    = 0b00001000; //enable the MT dual rail power supply

    PORTE.DIR = 0b00000111;
    PORTE.OUT    = 0b00000000;

    PORTF.DIR |= 0b00000000; //leave PF0-3 as inputs, dont mess with /Reset
    PORTF.OUT    &= 0b01000000;
  */


  pinMode(AY0, OUTPUT);
  digitalWrite(AY0, LOW);
  pinMode(AY1, OUTPUT);
  digitalWrite(AY1, LOW);
  pinMode(AY2, OUTPUT);
  digitalWrite(AY2, LOW);

  pinMode(AX0, OUTPUT);
  digitalWrite(AX0, LOW);
  pinMode(AX1, OUTPUT);
  digitalWrite(AX1, LOW);
  pinMode(AX2, OUTPUT);
  digitalWrite(AX2, LOW);
  pinMode(AX3, OUTPUT);
  digitalWrite(AX3, LOW);


  pinMode(CS_A, OUTPUT);
  digitalWrite(CS_A, HIGH);
  pinMode(CS_B, OUTPUT);
  digitalWrite(CS_B, HIGH);
  pinMode(CS_C, OUTPUT);
  digitalWrite(CS_C, HIGH);
  pinMode(CS_D, OUTPUT);
  digitalWrite(CS_D, HIGH);
  pinMode(CS_E, OUTPUT);
  digitalWrite(CS_E, HIGH);
  pinMode(CS_F, OUTPUT);
  digitalWrite(CS_F, HIGH);
  pinMode(CS_G, OUTPUT);
  digitalWrite(CS_G, HIGH);
  pinMode(CS_H, OUTPUT);
  digitalWrite(CS_H, HIGH);
  pinMode(CS_I, OUTPUT);
  digitalWrite(CS_I, HIGH);

  pinMode(RESET, OUTPUT);   //all of this just sets up all these pins as outputs and drives them LOW
  digitalWrite(RESET, HIGH); //I'm pretty sure Arduino IDE does this automatically but I wouldn't count on it
  delayMicroseconds(40);
  digitalWrite(RESET, LOW);
  


  pinMode(PWR_ENABLE1, OUTPUT);
  digitalWrite(PWR_ENABLE1, HIGH);

  pinMode(DATA, OUTPUT);
  digitalWrite(DATA, HIGH);
  pinMode(STROBE, OUTPUT);
  //digitalWrite(STROBE, LOW);

  pinMode(GP_PF0, OUTPUT);
  digitalWrite(GP_PF0, LOW);

  clearConnections();

}


void loop() {
  
  //clearBuffers();

  if (stayInConnectionMenu == 1) {
    getX();
  } else {
if (stayInConnectionMenu == -1) {
  showSpecialFunctionsMenu();
  selectMenuItem();
}else{
    showMenuOptions();
    selectMenuItem();
  }

}
}

int findPath (int breadRow1, int breadRow2) {



  if (breadRow1 == breadRow2) {
    return -1;
  }

  if (breadRow1 > breadRow2) {
    int breadRowTemp1 = breadRow1;
    breadRow1 = breadRow2;
    breadRow2 = breadRowTemp1;

  }

  chip1 = breadRow1 / 8;
  chip2 = breadRow2 / 8;


  if (chip2 - chip1 == 5) {
    int breadRowTemp1 = breadRow1;
    breadRow1 = breadRow2;
    breadRow2 = breadRowTemp1;
  }

  byte Xpin1 = 0;
  byte Ypin1 = breadRow1 % 8;

  byte Xpin2 = 0;
  byte Ypin2 = breadRow2 % 8;

  altPath = 0;
 
  int breadRowTemp2 = breadRow2;

  for (int i = 0; i < 17; i++) {
    //Serial1.println(i);
    if (i == 16) {

      breadRow2 = (breadRow1 + 16) % 64;
      altPath = 1;


      chip1 = breadRow1 / 8;
      Ypin1 = breadRow1 % 8;
      chip2 = breadRow2 / 8;
      Ypin2 = breadRow2 % 8;
      Serial1.println("Those chips don't have a direct connection,");
      Serial1.print("connecting through intermediate row ");
      Serial1.println(breadRow2);
      i = 0;

    }

    if (0) {        //only runs from the goto label
redoIt:

      breadRow1 = breadRow2;
      breadRow2 = breadRowTemp2;
      Serial1.println(breadRow1);
      Serial1.println(breadRow2);
      chip1 = breadRow1 / 8;
      Ypin1 = breadRow1 % 8;
      Ypin2 = breadRow2 % 8;
      chip2 = breadRow2 / 8;
      altPath = 0;
      i = 0;
    }


    if ((((matrixArrayX[chip1][i] - 'A') == chip2) && (availableConnections[chip1][i] == dataLine)) || ((chip1 == chip2) && (availableConnections[chip1][i % 16] == 1))) {

      Xpin1 = i;
      Xpin2 = Xpin1;


      if (dataLine == 1) {
        availableConnections[chip1][i % 16] = 0;
        availableConnections[chip2][i % 16] = 0;

        for (int l = 0; l < 4; l++) {
          if (connections[chip1][Ypin1][l] == -1) {
            connections[chip1][Ypin1][l] = breadRow2;
            break;
          }
        }
        for (int k = 0; k < 4; k++) {
          if (connections[chip2][Ypin2][k] == -1) {
            connections[chip2][Ypin2][k] = breadRow1;
            break;
          }
        }

      } else if (dataLine == 0) {


        availableConnections[chip1][i % 16] = 1;
        availableConnections[chip2][i % 16] = 1;

        for (int k = 0; k < 4; k++) {
          if (connections[chip1][Ypin1][k] == breadRow2) {
            connections[chip1][Ypin1][k] = -1;
            break;
          }
        }
        for (int l = 0; l < 4; l++) {
          if (connections[chip2][Ypin2][l] == breadRow1) {
            connections[chip2][Ypin2][l] = -1;
            break;
          }
        }
      }

      if (Xpin1 >= 8) {
        Xaddr1 = Xpin1 + 2;
      } else {
        Xaddr1 = Xpin1;
      }
      
      Yaddr1 = breadRow1 % 8;



      // Serial1.println(altPath);
      //Serial1.print("??????");
      Serial1.print(chipToChar(chip1));
      Serial1.print("\t");
      Serial1.print(Xaddr1);
      Serial1.print(" ");
      Serial1.print(Xpin1);
      Serial1.print("\t");
      Serial1.print(Yaddr1);
      Serial1.print(" ");
      Serial1.println(Ypin1);

      setAddress(Xaddr1, Yaddr1, chipToChar(breadRow1 / 8));

      if (Xpin2 >= 8) {         //this is a hack but it works until i can figure out why the x connections that are 2 chips away only work the 3rd time you send the command
        Xaddr2 = Xpin2 + 2;
      } else {
        Xaddr2 = Xpin2;
      }


      Yaddr2 = breadRow2 % 8;
      setAddress(Xaddr2, Yaddr2, chipToChar(chip2));

      Serial1.print(chipToChar(chip2));
      Serial1.print("\t");
      Serial1.print(Xaddr2);
      Serial1.print(" ");
      Serial1.print(Xpin2);
      Serial1.print("\t");
      Serial1.print(Yaddr2);
      Serial1.print(" ");
      Serial1.println(Ypin2);


      if (altPath >= 1) {
        i = 0;
        goto redoIt;
      } else {
        break;
      }

    }

  }

}


void showMenuOptions(void) {

  Serial1.println(" ");

  Serial1.println("Connect Nodes \t\t\tc");
  Serial1.println("Disconnect Nodes \t\td");
  Serial1.println("Show Frontend Connections \ty");
  Serial1.println("Show Backend Connections \tx");
  Serial1.println("Reset Connections\t\tr");
  Serial1.println("Special Funtions Menu\t\tf");
  Serial1.println("Back to Menu\t\t\tm");
  Serial1.println(" ");


}

void selectMenuItem(void) {

  //altPath = -1;
  while (!Serial1.available());    //this just keeps looping if there's nothing in the serial buffer, so it waits for you choose an item

  for (int i = 0; i < bufLength; i++) {   //clears the serial buffers by filling them with spaces
    serialBuffer[i] = ' ';
  }
  Serial1.readBytesUntil('\n', serialBuffer, bufLength);

  if (isDigit(serialBuffer[0]) == true) {
    dataLine = 1;
    stayInConnectionMenu = 1;
    getX();
  }

  switch (tolower(serialBuffer[0])) {

    case 'm':
        stayInConnectionMenu = 0;
        return;
        
    case 'c':
      dataLine = 1;
      stayInConnectionMenu = 1;
      getX();
      break;

    case 'd':
      dataLine = 0;
      stayInConnectionMenu = 1;
      getX();
      break;

    case 'r':
      clearConnections();
      Serial1.print ("Cleared!\n");
      break;

    case 'x':
      showArrays();
      break;
      
    case 'y':
      showConnections();
      break;

    case 'f':
      stayInConnectionMenu = -1;
      break;  

      
  }
  clearBuffers();
}

void showSpecialFunctionsMenu (void) {

  Serial1.println(" ");
  Serial1.println("Power Supplies ON \t\ti");
  Serial1.println("Power Supplies OFF \t\to");
  Serial1.println("Potentiometer \t\t\tp");
  Serial1.println("Analog Read\t\t\tv");
  Serial1.println("GPIO \t\t\t\tg");
  Serial1.println("Back to Menu\t\t\tm");
  Serial1.println(" ");

  
}


void getX() {     //this is just to get values from the serial monitor (which isnt a particularly nice way to set the switches)
  //                  dealing with inputs to the serial monitor is almost always a shit show, as you will see below
  Serial1.println(" ");
  if (dataLine == 0) {
    Serial1.print("Disconnect ");
  } else {
    Serial1.print("Connect ");
  }
  Serial1.println("rows");


  clearBuffers();

  int shift = 0;
  

  while (!Serial1.available());    //this just keeps looping if there's nothing in the serial buffer, so it waits for you to send some data

  Serial1.readBytesUntil('\n', serialBuffer, bufLength); //reads chars one at a time and puts them into the array serialBuffer
  //                                                        until it reads an \n or it reaches the end (bufLength)
  if (isDigit(serialBuffer[0]) != true) {


    switch (tolower(serialBuffer[0])) {
      case 'm':
        Serial1.println("\n");
        stayInConnectionMenu = 0;
        return;

      case 'd':
        dataLine = 0;
        return;

      case 'c':
        dataLine = 1;
        return;

      case 'y':
        showConnections();
        return;
        
      case 'x':
        showArrays();
        break;
        
      case 'r':
       clearConnections();
        Serial1.println ("Cleared!\n");
        break;
        
      case't':    
        break;
        
      case'b':
        break;
        
      default:
        Serial1.println ("\nPlease enter a number");
        return;
    }
  }

  comma = -1;
  int bottomX = 0;
  int bottomY = 0;
  
  for (int i = shift; i < bufLength; i++) {  //this loop lets is enter values as "X,Y" instead of one at a time (it was super annoying to do it that way when testing)
    //                                         by taking one serialBuffer and then splitting it into separate X and Y serialBuffers

    if (serialBuffer[i] == ',') {     //loops through serialBuffer[] to look for a comma and sets "comma" to the position in the array
      comma = i;
      
      i++;
    }
    
    if (serialBuffer[i] == 'b') {     //loops through serialBuffer[] to look for a comma and sets "comma" to the position in the array
      if (comma == -1) {
        bottomX = 1;
      } else {
        bottomY = 1;
      }
      
      i++;
    }

    if (serialBuffer[i] == 't') {
      i++;
    }

    if (comma == -1) {                    //if it hasnt found a comma, then this part of the buffer is for the X address buffer

      serialBufferX[i] = serialBuffer[i];
      
    } else {
      
      serialBufferY[i] = serialBuffer[i];
      
    }
  }

  int incomingValueX = atoi(serialBufferX);   //atoi converts a char array to an integer (Array TO Int)

  if (bottomX == 1) {
    incomingValueX += 32;
  }
  
  int incomingValueY = atoi(serialBufferY);

  if (bottomY == 1) {
    incomingValueY += 32;
  }

  if (incomingValueX >= Xsize) {              //this checks to make sure the values you entered aren't above the maximum size specified in Xsize
    Serial1.print ("\nPlease enter a number for X between 0 and ");
    Serial1.println (Xsize - 1);
    return;
  }
  if (incomingValueY >= Ysize && comma > 0) { //the logical AND makes it only check if we put in a Y address separated by a comma
    Serial1.print ("\nPlease enter a number for Y between 0 and ");
    Serial1.println (Ysize - 1);
    return;
  }

  GbreadRow1 = incomingValueX;  //now that we know our inputs are good, we can put them into Xaddr and Yaddr

  GbreadRow2 = incomingValueY;

  if (findPath(GbreadRow1, GbreadRow2) == -1) {
    return;
  }

  if (comma > 0) {          //only prints a Y if you entered it here
    //Serial1.print("Y = ");
    //Serial1.println(Yaddr1);
    // Serial1.println(' ');
  }



  if (comma < 0) {        //if a Y wasnt entered comma will still be -1, call getY() to ask for one
    comma = -1;          //set the comma back to -1 for the next entry
  }



}

void setAddress (byte Xaddr, byte Yaddr, char chip) {



  digitalWrite(AX3, LOW);
  digitalWrite(AX2, LOW);
  digitalWrite(AX1, LOW);
  digitalWrite(AX0, LOW);

  digitalWrite(AY2, LOW);
  digitalWrite(AY1, LOW);
  digitalWrite(AY0, LOW);


  selectChip(chip);            //datasheet says CS_ should be set while setting up address lines, not sure why though
  delayMicroseconds(40);

  digitalWrite(AX3, HIGH && (Xaddr & B00001000));   //this only writes the line high if that bit is set in binary value of Xaddr
  Serial1.print (HIGH && Xaddr & B00001000);
  digitalWrite(AX2, HIGH && (Xaddr & B00000100));   //for example Xaddr = 6 or B00000110          //note: && is logical AND, and & is bitwise AND
  Serial1.print (HIGH && Xaddr & B00000100);
  digitalWrite(AX1, HIGH && (Xaddr & B00000010));   //this bitwise ANDs Xaddr and a binary value with just one bit set
  Serial1.print (HIGH && Xaddr & B00000010);
  digitalWrite(AX0, HIGH && (Xaddr & B00000001));   //so we get          Xaddr   00000110
  Serial1.println (HIGH && Xaddr & B00000001);                                    //                                                          AND bit selector   00001000 = 0
  digitalWrite(AY2, HIGH && (Yaddr & B00000100));   //then we AND that again with HIGH (which is just interpreted as 1)

  digitalWrite(AY1, HIGH && (Yaddr & B00000010));   //to get 1(HIGH) && 0(the result from above) = 0 (which is LOW)

  digitalWrite(AY0, HIGH && (Yaddr & B00000001));   //we do that for each bit to end up with the address lines LLLLLHHL

  delayMicroseconds(50);      //allow the lines to settle

  strobeItIn();   //we could probably do this without passing "chip" and just do all the strobing on both together,
  //                    but I don't necessarily want to make MT8816 ignore that many garbage signals with CS_ LOW
  //deselectChip();


}

void strobeItIn (void) {

  if (dataLine == 0) {
    digitalWrite(DATA, LOW);
  } else {
    digitalWrite(DATA, HIGH);
  }

  //pinMode(STROBE, OUTPUT);
  delayMicroseconds(100);        //Hold time in the datasheet for the MT8816 says this only needs to be 10 nanoseconds
  digitalWrite(STROBE, HIGH);  //but we're not super concerned with speed so I'll give it 1000X more just to be safe
  delayMicroseconds(400);        //Strobe has to be a minimum of 20 nanoseconds, but I dont want to think about the
  //Serial1.println("!!!!!!!!!!!!");
  digitalWrite(STROBE, LOW);   //fact that light only travels like 4 meters in that time through copper
  //pinMode(STROBE, OUTPUT);
  delayMicroseconds(80);
  //digitalWrite(DATA, LOW);
  //delayMicroseconds(30);


}

void selectChip (char chip)  {        //asserts whichever chip select line we send it

  chip = chipToChar(chip);

  digitalWrite(CS_A, LOW);
  digitalWrite(CS_B, LOW);
  digitalWrite(CS_C, LOW);
  digitalWrite(CS_D, LOW);
  digitalWrite(CS_E, LOW);
  digitalWrite(CS_F, LOW);
  digitalWrite(CS_G, LOW);
  digitalWrite(CS_H, LOW);
  digitalWrite(CS_I, LOW);

  delayMicroseconds(30);
  Serial1.print(chipToChar(chip));

  if (chip == 'A' || chip == 'a') {
    digitalWrite(CS_A, HIGH);      //datasheet says CS_ should be set while setting up address lines, not sure why though
    //Serial1.print(chipToChar(chip));
    return;
  }
  if (chip == 'B' || chip == 'b') {
    digitalWrite(CS_B, HIGH);
    return;
  }
  if (chip == 'C' || chip == 'c') {
    digitalWrite(CS_C, HIGH);
    return;
  }
  if (chip == 'D' || chip == 'd') {
    digitalWrite(CS_D, HIGH);
    return;
  }
  if (chip == 'E' || chip == 'e') {
    digitalWrite(CS_E, HIGH);
    return;
  }
  if (chip == 'F' || chip == 'f') {
    digitalWrite(CS_F, HIGH);
    return;
  }
  if (chip == 'G' || chip == 'g') {
    digitalWrite(CS_G, HIGH);
    return;
  }
  if (chip == 'H' || chip == 'h') {
    digitalWrite(CS_H, HIGH);
    return;
  }
  if (chip == 'I' || chip == 'i') {
    digitalWrite(CS_I, HIGH);
    return;
  }

}

void deselectChip (void)  {         //this should be fairly obvious

  digitalWrite(CS_A, LOW);
  digitalWrite(CS_B, LOW);
  digitalWrite(CS_C, LOW);
  digitalWrite(CS_D, LOW);
  digitalWrite(CS_E, LOW);
  digitalWrite(CS_F, LOW);
  digitalWrite(CS_G, LOW);
  digitalWrite(CS_H, LOW);
  digitalWrite(CS_I, LOW);
  return;
}

void clearConnections (void)  {    //when you send a reset pulse, all previous connections are cleared on whichever chip is CS_ed but we'll do both for now

  digitalWrite(CS_A, HIGH);
  digitalWrite(CS_B, HIGH);
  digitalWrite(CS_C, HIGH);
  digitalWrite(CS_D, HIGH);
  digitalWrite(CS_E, HIGH);
  digitalWrite(CS_F, HIGH);
  digitalWrite(CS_G, HIGH);
  digitalWrite(CS_H, HIGH);
  digitalWrite(CS_I, HIGH);

  digitalWrite(RESET, HIGH);
  delayMicroseconds(200);     //datasheet says 40 nanoseconds minimum, this is a lot more than that
  digitalWrite(RESET, LOW);

  digitalWrite(CS_A, LOW);
  digitalWrite(CS_B, LOW);
  digitalWrite(CS_C, LOW);
  digitalWrite(CS_D, LOW);
  digitalWrite(CS_E, LOW);
  digitalWrite(CS_F, LOW);
  digitalWrite(CS_G, LOW);
  digitalWrite(CS_H, LOW);
  digitalWrite(CS_I, LOW);

  for (int i = 0; i < 8; i++) {
    for (int j = 0; j < 8; j++) {
      for (int k = 0; k < 4; k++) {
        connections[i][j][k] = -1;
      }
    }
  }

  for (int i = 0; i < 8; i++) {
    for (int j = 0; j < 16; j++) {
      availableConnections[i][j] = 1;
    }
  }


}

void clearBuffers (void) {

  for (int i = 0; i < bufLength; i++) {   //clears the serial buffers by filling them with spaces
    serialBuffer[i] = ' ';
    serialBufferX[i] = ' ';
    serialBufferY[i] = ' ';
  }

  /* while (Serial1.available() > 0) {    //this is just a trick to clear the serial buffer (if we typed in a really long string it would just keep entering them one after another)
     Serial1.print(Serial1.read());                    //it reads the serial buffer and then throws away the values, just to clear it
     delay(100);
    }*/
  Serial1.end();         //maybe it's just easier to stop and start the serial connection
  Serial1.begin(115200);

}

char chipToChar (int chip) {

  switch (chip) {
    case 0:
      return 'A';
    case 1:
      return 'B';
    case 2:
      return 'C';
    case 3:
      return 'D';
    case 4:
      return 'E';
    case 5:
      return 'F';
    case 6:
      return 'G';
    case 7:
      return 'H';
    case 8:
      return 'I';
  }
}

void showArrays (void) {

  for (int i = 0; i < 8; i++) {

    Serial1.print ("Chip ");
    Serial1.print (chipToChar(i));
    Serial1.print ("\t");

    for (int j = 0; j < 16; j++) {
      if (chipToChar(i) < matrixArrayX[i][j]) {
        Serial1.print (chipToChar(i));
        Serial1.print (matrixArrayX[i][j]);
      } else {
        Serial1.print (matrixArrayX[i][j]);
        Serial1.print (chipToChar(i));
      }
      Serial1.print (" ");
      Serial1.print (!availableConnections [i][j]);
      Serial1.print ("\t");
    }
    Serial1.println(" ");
  }
}

void showConnections (void) {

  int count = 0;
  int countConn = 0;
  int countDig = 0;
  char chipLetter = 'A';
  for (int i = 0; i < 8; i++) {
    Serial1.print("Chip ");
    Serial1.print(chipLetter);
    Serial1.print("\t");
    chipLetter++;

    for (int j = 0; j < 8; j++) {
      countDig = 0;
      countConn = 0;
      Serial1.print(count);
      if (count <= 9) Serial1.print (" ");

      count++;
      Serial1.print(" ");
      if (connections[i][j][0] == -1 && connections[i][j][1] == -1 && connections[i][j][2] == -1 && connections[i][j][3] == -1) {
        Serial1.print("X\t");
      } else {
        countDig = 0;
        for (int k = 0; k < 4; k++) {
          if (connections[i][j][k] != -1) {

            if (countConn >= 1 && countConn < 4) {
              Serial1.print(',');

              countDig++;
            }
            countConn++;
            Serial1.print(connections[i][j][k]);

            if (connections[i][j][k] >= 9) {
              countDig++;
            }
            countDig++;
          }

        }
        if (countDig <= 4) {
          Serial1.print("\t");
          //Serial1.print(countDig);
          countDig = 0;
        }
      }
      Serial1.print("\t");
    }
    //if (count == 32) Serial1.print ("\n");
    Serial1.println(" ");
  }


}

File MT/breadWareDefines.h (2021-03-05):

#define CS_A PIN_PB0
#define CS_B PIN_PB1
#define CS_C PIN_PB2
#define CS_D PIN_PB3
#define CS_E PIN_PB4
#define CS_F PIN_PB5
#define CS_G PIN_PC4
#define CS_H PIN_PC5
#define CS_I PIN_PC6

#define DATA PIN_PE0
#define RESET PIN_PE1
#define STROBE PIN_PE2

#define AX0 PIN_PA0
#define AX1 PIN_PA1
#define AX2 PIN_PA2
#define AX3 PIN_PA3

#define AY0 PIN_PA4
#define AY1 PIN_PA5
#define AY2 PIN_PA6


#define GP_PF0 PIN_PF0    //anything that starts with GP_ goes to
#define GP_PF1 PIN_PF1    //the matrix chip on the control board
#define GP_PF2 PIN_PF2    //for "General Purpose"
#define GP_PF3 PIN_PF3

#define ADC_VDIVO PIN_PD0    //for sensing voltages (after getting voltage
#define ADC_VDIV1 PIN_PD1    //divided by 5)
#define ADC_BIAS PIN_PD7     //sets the bias so you can read negative voltages

#define PWR_SENSE1 PIN_PD2   //senses dual power supply voltage / 5
#define PWR_ENABLE1 PIN_PD3  //turns on dual power rails for matrix chips
#define PWR_SENSE2 PIN_PD4   //senses power supply voltage / 5
#define PWR_ENABLE2 PIN_PD5  //turns on adjustable power supply


#define USB_RX PIN_PC0
#define USB_TX PIN_PC1

#define I2C_SDA PIN_PC2
#define I2C_SCL PIN_PC3

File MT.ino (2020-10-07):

#define chipSelectA 14
#define chipSelectB 18

#define dataA 15
#define strobeA 16
#define dataB 19
#define strobeB 20
#define rst 17

#define AX0 5
#define AX1 6
#define AX2 7
#define AX3 8

#define AY0 2
#define AY1 3
#define AY2 4

//Address lines for chip A and B will be connected together
//we can use the chipSelect lines to decide which chip to update
/*
  The pinout for the dev board
  Left side control lines (top to bottom)

  Chip Select A
  DATa A
  STroBe A
  ReSeT
  Chip Select B
  DATa B
  STroBe B
  VDD +
  VSS GND
  VEE -

  Bottom address lines (left to right)

  Y0 A
  Y1 A
  Y2 A
  X0 A
  X1 A
  X2 A
  X3 A
  Y0 B
  Y1 B
  Y2 B
  X0 B
  X1 B
  X2 B
  X3 B

*/

char chip = 'A';

byte Xaddr = 0;
byte Yaddr = 0;

int Xsize = 16;
int Ysize = 8;

int X = 0;
int Y = 0;

int comma = -1;

int stayInConnectionMenu = 0;   //if this is 1, it skips the menu so we can keep adding connections

const byte bufLength = 8;

char serialBuffer[bufLength];
char serialBufferX[bufLength];
char serialBufferY[bufLength];

char connectionsChip[100]; //stores which chip each connection was made on
int connectionsX [100];   //
int connectionsY [100];   //these should match each other by index so connectionsX[0][5] should be connected to connectionsY[0][5]
int connIndex = 0; //this stores the index of last position (we only need one because X and Y should be the same)

void setup() {

  Serial.begin (9600);

  pinMode(rst, OUTPUT);   //all of this just sets up all these pins as outputs and drives them LOW
  digitalWrite(rst, LOW); //I'm pretty sure Arduino IDE does this automatically but I wouldn't count on it

  pinMode(AY0, OUTPUT);
  digitalWrite(AY0, LOW);
  pinMode(AY1, OUTPUT);
  digitalWrite(AY1, LOW);
  pinMode(AY2, OUTPUT);
  digitalWrite(AY2, LOW);

  pinMode(AX0, OUTPUT);
  digitalWrite(AX0, LOW);
  pinMode(AX1, OUTPUT);
  digitalWrite(AX1, LOW);
  pinMode(AX2, OUTPUT);
  digitalWrite(AX2, LOW);
  pinMode(AX3, OUTPUT);
  digitalWrite(AX3, LOW);


  pinMode(chipSelectA, OUTPUT);
  digitalWrite(chipSelectA, LOW);
  pinMode(chipSelectB, OUTPUT);
  digitalWrite(chipSelectB, LOW);

  pinMode(dataA, OUTPUT);
  digitalWrite(dataA, LOW);
  pinMode(strobeA, OUTPUT);
  digitalWrite(strobeA, LOW);

  pinMode(dataB, OUTPUT);
  digitalWrite(dataB, LOW);
  pinMode(strobeB, OUTPUT);
  digitalWrite(strobeB, LOW);
}


void loop() {
  clearBuffers();
  if (stayInConnectionMenu == 1) {
    getX();
  } else {

    showMenuOptions();
    selectMenuItem();
  }


  //Serial.print("Cool\n");

}

void showMenuOptions(void) {

  //Serial.println(" ");
  Serial.print("Select Chip \t\ta/b\t Currently ");
  Serial.println(chip);
  Serial.println("Connect Nodes \t\tc");
  Serial.println("Show Connections \ts");
  Serial.println("Reset Connections\tr");
  Serial.println("Back to Menu\t\tm");
  Serial.println(" ");


}

void selectMenuItem(void) {


  while (!Serial.available());    //this just keeps looping if there's nothing in the serial buffer, so it waits for you choose an item

  for (int i = 0; i < bufLength; i++) {   //clears the serial buffers by filling them with spaces
    serialBuffer[i] = ' ';
  }
  Serial.readBytesUntil('\n', serialBuffer, bufLength);

  switch (tolower(serialBuffer[0])) {

    case 'c':
      stayInConnectionMenu = 1;
      getX();
      break;

    case 'r':
      clearConnections();
      Serial.println ("Cleared!\n");
      break;

    case 'a':
      chip = 'A';
      break;

    case 'b':
      chip = 'B';
      break;

    case 's':
      showConnections();

      break;
  }
  clearBuffers();
}



void getX() {     //this is just to get values from the serial monitor (which isnt a particularly nice way to set the switches)
  //                  dealing with inputs to the serial monitor is almost always a shit show, as you will see below

  Serial.print("Connect X [0-15] to Y [0-7] on chip ");
  Serial.println(chip);
  clearBuffers();

  int shift = 0;

  while (!Serial.available());    //this just keeps looping if there's nothing in the serial buffer, so it waits for you to send some data

  Serial.readBytesUntil('\n', serialBuffer, bufLength); //reads chars one at a time and puts them into the array serialBuffer
  //                                                        until it reads an \n or it reaches the end (bufLength)
  if (isDigit(serialBuffer[0]) != true) {


    switch (tolower(serialBuffer[0])) {
      case 'm':
        Serial.println("\n");
        stayInConnectionMenu = 0;
        return;

      case'a':
        chip = 'A';
        Serial.println("Switched to chip A");
        shift++;
        break;

      case'b':
        chip = 'B';
        Serial.println("Switched to chip B");
        shift++;
        break;

      default:
        Serial.println ("\nPlease enter a number");
        return;
    }
  }

  comma = -1;

  for (int i = shift; i < bufLength; i++) {  //this loop lets is enter values as "X,Y" instead of one at a time (it was super annoying to do it that way when testing)
    //                                         by taking one serialBuffer and then splitting it into separate X and Y serialBuffers

    if (serialBuffer[i] == ',') {     //loops through serialBuffer[] to look for a comma and sets "comma" to the position in the array
      comma = i;
      i++;
    }

    if (comma == -1) {                    //if it hasnt found a comma, then this part of the buffer is for the X address buffer
      serialBufferX[i] = serialBuffer[i];
    } else {
      serialBufferY[i] = serialBuffer[i]; //if it has, then it start putting them into the Y address buffer
    }
  }

  int incomingValueX = atoi(serialBufferX);   //atoi converts a char array to an integer (Array TO Int)
  int incomingValueY = atoi(serialBufferY);

  if (incomingValueX >= Xsize) {              //this checks to make sure the values you entered aren't above the maximum size specified in Xsize
    Serial.print ("\nPlease enter a number for X between 0 and ");
    Serial.println (Xsize - 1);
    return;
  }
  if (incomingValueY >= Ysize && comma > 0) { //the logical AND makes it only check if we put in a Y address separated by a comma
    Serial.print ("\nPlease enter a number for Y between 0 and ");
    Serial.println (Ysize - 1);
    return;
  }

  Xaddr = atoi(serialBufferX);  //now that we know our inputs are good, we can put them into Xaddr and Yaddr
  Yaddr = atoi(serialBufferY);
  Serial.print("X = ");
  Serial.println(Xaddr);

  if (comma > 0) {          //only prints a Y if you entered it here
    Serial.print("Y = ");
    Serial.println(Yaddr);
    Serial.println(' ');
  }

  //Serial.println(' ');    //gives us some breathing room in the serial monitor output

  if (comma < 0) {        //if a Y wasnt entered comma will still be -1, call getY() to ask for one
    comma = -1;          //set the comma back to -1 for the next entry
    getY();
  }
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
